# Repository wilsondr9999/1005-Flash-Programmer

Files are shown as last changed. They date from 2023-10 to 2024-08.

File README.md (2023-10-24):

# Flash Programmer
Copyright © 2021 by Dan WIlson

This is a simple PCB, firmware, and software that can read and write binary image files to the Microchip SST39 series of flash ROMs.  These flash ROMs are one of the very few flash ROMs on the market that are still active production and in DIP packages, making them a popular replacement for the difficult-to-find AT28 series of EEPROMs.

This programmer handles the SST39SF010, SST39SF020, and SST39SF040 parts (128KB, 256KB, and 512KB respectively).

This programmer’s PCB design uses all through-hole parts for easy soldering.  The general design is based on Ben Eater’s [Arduino-based Flash Programmer](https://www.youtube.com/watch?v=K88pgWhEb1M), using a microcontroller and shift registers to increase the number of available outputs.  Ben’s microcontroller is the Arduino Nano, here I’m using a Microchip PIC16.

The firmware on the PIC16 implements a command protocol that runs over a serial interface.  The board contains a simple RS232 serial level shifter that allows the PC to communicate with the microcontroller.

On the PC, a command line program is provided to read and write to the flash memory.  The command line program is written in Visual C# with Visual Studio.

You can order the PCBs directly from Oshpark with [this](https://oshpark.com/import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) link.

Several different licenses apply to this repository and the files within.

All schematics and circuit board designs in the project (all KiCAD files) are licensed under the CERN Open Hardware License Version 2 - Strongly Reciprocal (CERN-OHL-S).

All software and firmware code in the project (all MPLAB and Visual Studio files) are licensed under the GNU Affero General Public License v3.0 (AGPL 3.0).

Bill of Materials, pictures, and documentation (i.e. all other files not covered by the other two licenses above) are licensed under the Creative Commons Attribution Share Alike 4.0 International License (CC-BY-SA-4.0).

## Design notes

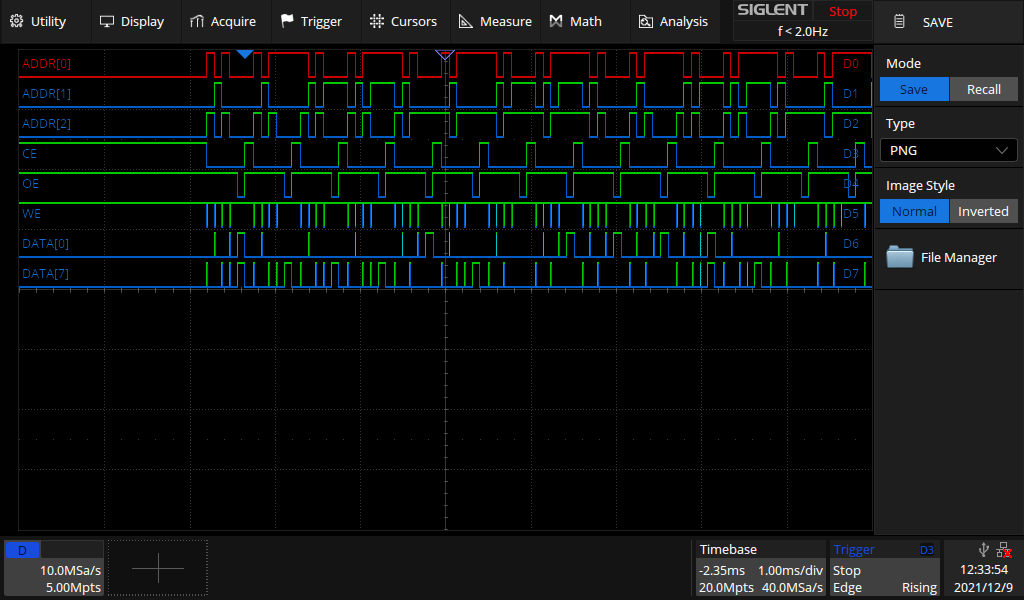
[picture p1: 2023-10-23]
Additional Files/Write2.png

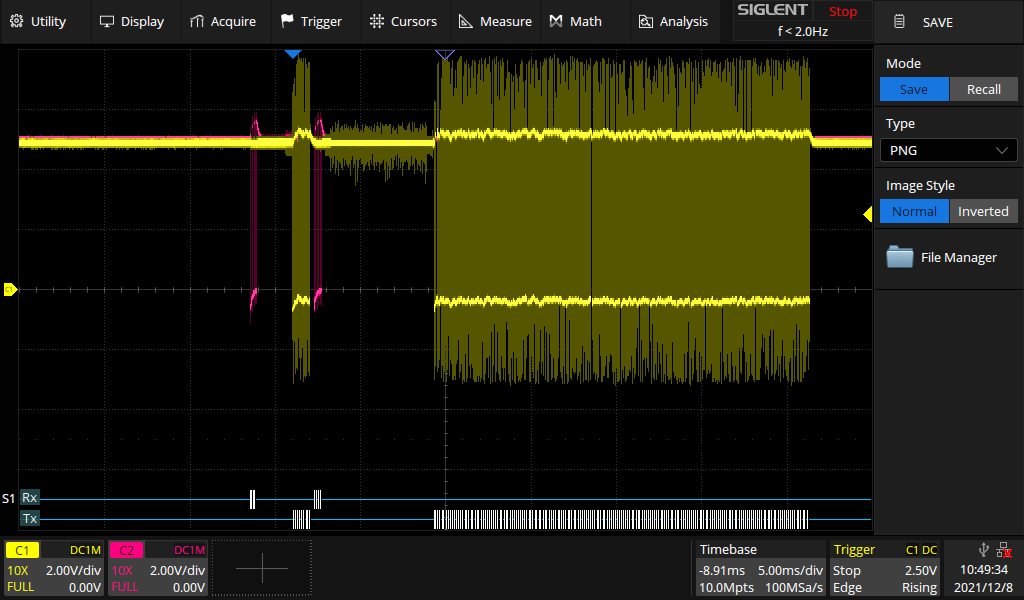
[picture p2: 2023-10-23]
Additional Files/8Mhz.png

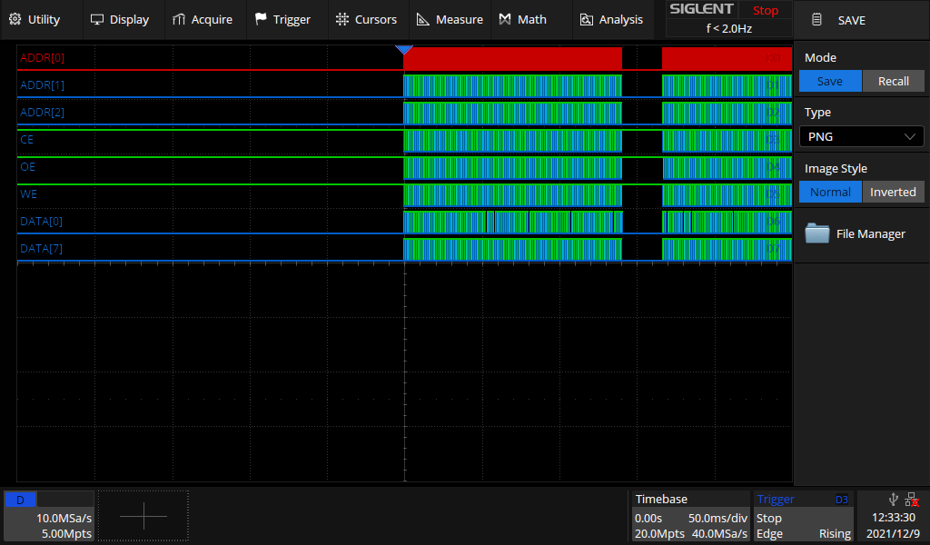
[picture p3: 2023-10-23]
Additional Files/Write1.png

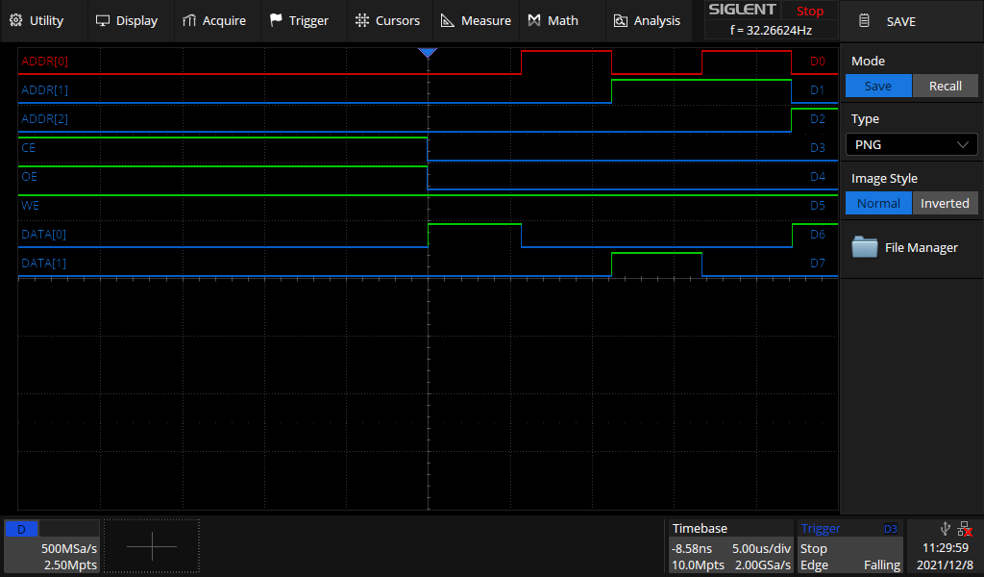
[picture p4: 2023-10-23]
Additional Files/ReadTiming.png

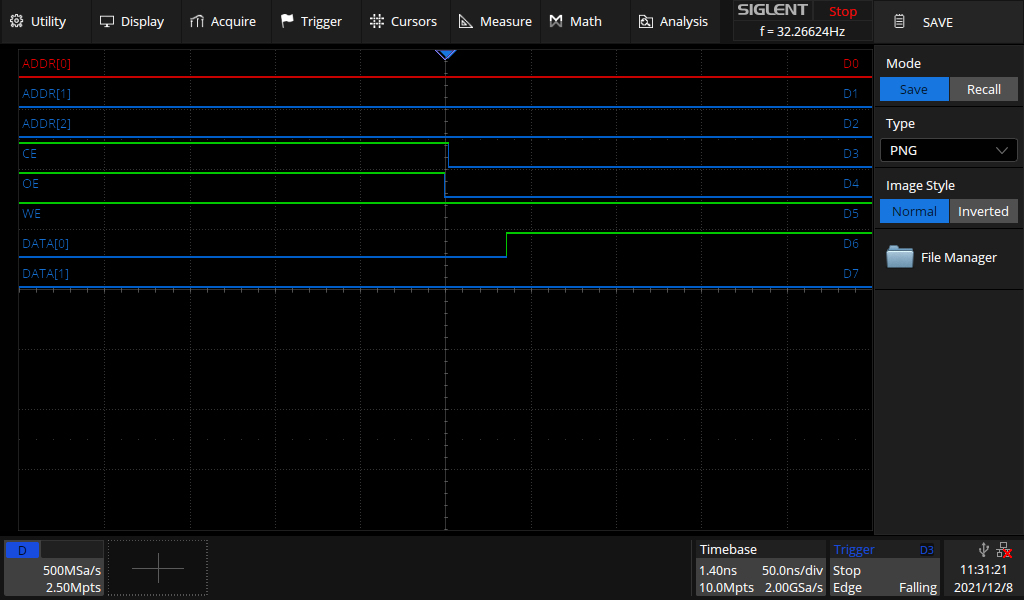
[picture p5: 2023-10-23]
Additional Files/ReadTiming2.png

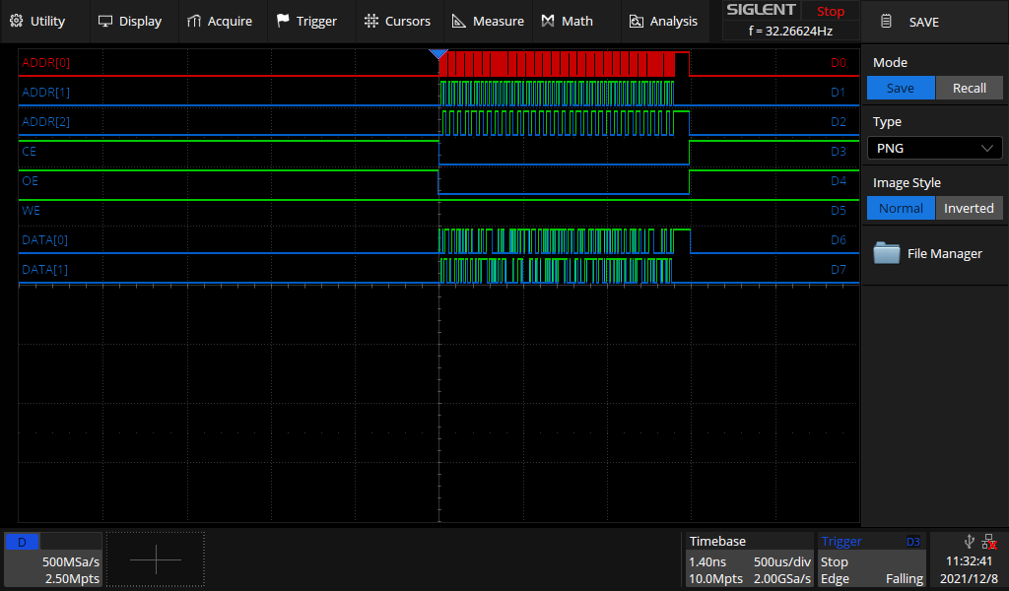
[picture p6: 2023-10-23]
Additional Files/PageRead.png

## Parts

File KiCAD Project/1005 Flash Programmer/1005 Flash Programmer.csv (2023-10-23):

Source: | C:\EE\Projects\1005 Flash Programmer\KiCAD Project\1005 Flash Programmer\1005 Flash Programmer.sch
Date: | 12/26/2021 11:18:50 AM
Tool: | Eeschema (5.1.12)-1
Generator: | C:\Program Files\KiCad\bin\scripting\plugins/bom_csv_grouped_by_value.py
Component Count: | 35
Individual Components:
Item | Qty | Reference(s) | Value | LibPart | Footprint | Datasheet | Category | DK_Datasheet_Link | DK_Detail_Page | Description | Digi-Key_PN | Family | MPN | Manufacturer | Status
 |  | C201 | 0.1uF | Device:C | Capacitor_THT:C_Disc_D4.7mm_W2.5mm_P5.00mm | ~ |  |  |  | CAP CER 0.1UF 50V X7R RADIAL | 445-173588-1-ND | Ceramic Capacitors | FG28X7R1H104KNT06 | TDK Corporation
 |  | C301 | 0.33uF | Device:C | Capacitor_THT:C_Disc_D5.1mm_W3.2mm_P5.00mm | ~ |  |  |  | CAP CER 0.33UF 50V X7R RADIAL | 445-180638-1-ND | Ceramic Capacitors | FA24X7R1H334KNU06 | TDK Corporation
 |  | C302 | 0.1uF | Device:C | Capacitor_THT:C_Disc_D4.7mm_W2.5mm_P5.00mm | ~ |  |  |  | CAP CER 0.1UF 50V X7R RADIAL | 445-173588-1-ND | Ceramic Capacitors | FG28X7R1H104KNT06 | TDK Corporation
 |  | C401 | 0.1uF | Device:C | Capacitor_THT:C_Disc_D4.7mm_W2.5mm_P5.00mm | ~ |  |  |  | CAP CER 0.1UF 50V X7R RADIAL | 445-173588-1-ND | Ceramic Capacitors | FG28X7R1H104KNT06 | TDK Corporation
 |  | C501 | 0.1uF | Device:C | Capacitor_THT:C_Disc_D4.7mm_W2.5mm_P5.00mm | ~ |  |  |  | CAP CER 0.1UF 50V X7R RADIAL | 445-173588-1-ND | Ceramic Capacitors | FG28X7R1H104KNT06 | TDK Corporation
 |  | C502 | 0.1uF | Device:C | Capacitor_THT:C_Disc_D4.7mm_W2.5mm_P5.00mm | ~ |  |  |  | CAP CER 0.1UF 50V X7R RADIAL | 445-173588-1-ND | Ceramic Capacitors | FG28X7R1H104KNT06 | TDK Corporation
 |  | C601 | 0.1uF | Device:C | Capacitor_THT:C_Disc_D4.7mm_W2.5mm_P5.00mm | ~ |  |  |  | CAP CER 0.1UF 50V X7R RADIAL | 445-173588-1-ND | Ceramic Capacitors | FG28X7R1H104KNT06 | TDK Corporation
 |  | D201 | 1N4148 | Diode:1N4148 | Diode_THT:D_DO-35_SOD27_P7.62mm_Horizontal | https://assets.nexperia.com/documents/data-sheet/1N4148_1N4448.pdf |  | https://rocelec.widen.net/view/pdf/bhc41r7lwc/ONSM-S-A0003539415-1.pdf?t.download=true&u=5oefqw |  | DIODE GEN PURP 100V 200MA DO35 | 1N4148FS-ND | Diodes - Rectifiers - Single | 1N4148 | onsemi
 |  | D301 | LED | Device:LED | LED_THT:LED_D5.0mm | https://www.lumex.com/spec/SSL-LX5093USBD.pdf |  | https://www.lumex.com/spec/SSL-LX5093USBD.pdf |  | LED BLUE DIFFUSED T-1 3/4 T/H | 67-1751-ND | LED Indication - Discrete | SSL-LX5093USBD | Lumex Opto/Components Inc.
 |  | D401 | LED | Device:LED | LED_THT:LED_D5.0mm | https://media.digikey.com/pdf/Data%20Sheets/Lite-On%20PDFs/LTL-307A.pdf |  | https://media.digikey.com/pdf/Data%20Sheets/Lite-On%20PDFs/LTL-307A.pdf |  | LED AMBER DIFFUSED T-1 3/4 T/H | 160-1949-ND | LED Indication - Discrete | LTL-307A | LITEON
 |  | D402 | LED | Device:LED | LED_THT:LED_D5.0mm | https://media.digikey.com/pdf/Data%20Sheets/Lite-On%20PDFs/LTL-4233.pdf |  | https://media.digikey.com/pdf/Data%20Sheets/Lite-On%20PDFs/LTL-4233.pdf |  | LED GREEN DIFFUSED T-1 3/4 T/H | 160-1130-ND | LED Indication - Discrete | LTL-4233 | LITEON
 |  | H101 | MountingHole | Mechanical:MountingHole | MountingHole:MountingHole_3.2mm_M3 | ~
 |  | H102 | MountingHole | Mechanical:MountingHole | MountingHole:MountingHole_3.2mm_M3 | ~
 |  | H103 | MountingHole | Mechanical:MountingHole | MountingHole:MountingHole_3.2mm_M3 | ~
 |  | H104 | MountingHole | Mechanical:MountingHole | MountingHole:MountingHole_3.2mm_M3 | ~
 |  | J201 | A-2004-2-4-LP-N-R | dk_Modular-Connectors-Jacks:54602-908LF | digikey-footprints:Ethernet_Jack_54602-908LF |  | Connectors, Interconnects |  | /product-detail/en/amphenol-icc-fci/54602-908LF/609-1046-ND/1001360 | CONN MOD JACK 8P8C R/A UNSHLD | AE10384-ND | Modular Connectors - Jacks | A-2004-2-4-LP-N-R | Amphenol ICC (FCI) | Active
 |  | J301 | Barrel_Jack_Switch | Connector:Barrel_Jack_Switch | digikey-footprints:Barrel_Jack_5.5mmODx2.1mmID_PJ-102A | https://www.cuidevices.com/product/resource/pj-102b.pdf |  | https://www.cuidevices.com/product/resource/pj-102b.pdf |  | CONN PWR JACK 2.5X5.5MM SOLDER | CP-102B-ND | Barrel - Power Connectors | PJ-102B | CUI Devices
 |  | J401 | ICSP | Connector_Generic:Conn_01x05 | Connector_PinHeader_2.54mm:PinHeader_1x05_P2.54mm_Vertical | https://app.adam-tech.com/products/download/data_sheet/201605/ph1-xx-ua-data-sheet.pdf |  | https://app.adam-tech.com/products/download/data_sheet/201605/ph1-xx-ua-data-sheet.pdf |  | CONN HEADER VERT 5POS 2.54MM | 2057-PH1-05-UA-ND | Rectangular Connectors - Headers, Male Pins | PH1-05-UA | Adam Tech
 |  | J601 | 32-6554-10 | DW_Library:32-6554-10 | DW_Footprint:32-6554-10 | https://www.arieselec.com/wp-content/uploads/2020/02/10001-universal-dip-zif-test-socket.pdf |  | https://www.arieselec.com/wp-content/uploads/2020/02/10001-universal-dip-zif-test-socket.pdf |  | CONN IC DIP SOCKET ZIF 32POS TIN | A304-ND | Sockets for ICs, Transistors | 32-6554-10 | Aries Electronics
 |  | Q201 | BC558 | Transistor_BJT:BC558 | Package_TO_SOT_THT:TO-92_Inline | https://www.onsemi.com/pub/Collateral/BC556BTA-D.pdf |  | https://www.nteinc.com/specs/original/BC558.pdf |  | TRANS PNP 30V 100MA TO92-3 | 2368-BC558-ND | Transistors - Bipolar (BJT) - Songle | BC558 | NTE Electronics, Inc
 |  | Q202 | BC548 | Transistor_BJT:BC548 | Package_TO_SOT_THT:TO-92_Inline | https://www.onsemi.com/pub/Collateral/BC550-D.pdf |  | https://rocelec.widen.net/view/pdf/q1kc0zm1fe/FAIRS24942-1.pdf?t.download=true&u=5oefqw |  | TRANS NPN 30V 100MA TO92-3 | 2156-BC548-FS-ND | Transistors - Bipolar (BJT) - Songle | BC548 | Fairchild Semiconductor
 |  | R201 | 10K | Device:R_US | Resistor_THT:R_Axial_DIN0207_L6.3mm_D2.5mm_P10.16mm_Horizontal | ~ |  | https://www.yageo.com/upload/media/product/productsearch/datasheet/lr/YAGEO%20MFR_datasheet_2021v1.pdf |  | RES 10K OHM 1% 1/4W AXIAL | 10.0KXBK-ND | Through Hole Resistors | MFR-25FBF52-10K | YAGEO
 |  | R202 | 10K | Device:R_US | Resistor_THT:R_Axial_DIN0207_L6.3mm_D2.5mm_P10.16mm_Horizontal | ~ |  | https://www.yageo.com/upload/media/product/productsearch/datasheet/lr/YAGEO%20MFR_datasheet_2021v1.pdf |  | RES 10K OHM 1% 1/4W AXIAL | 10.0KXBK-ND | Through Hole Resistors | MFR-25FBF52-10K | YAGEO
 |  | R203 | 4.7K | Device:R_US | Resistor_THT:R_Axial_DIN0207_L6.3mm_D2.5mm_P10.16mm_Horizontal | ~ |  | https://www.yageo.com/upload/media/product/productsearch/datasheet/lr/YAGEO%20MFR_datasheet_2021v1.pdf |  | RES 4.7K OHM 1% 1/4W AXIAL | MFR-25FBF52-4K7-ND | Through Hole Resistors | MFR-25FBF52-4K7 | YAGEO
 |  | R204 | 10K | Device:R_US | Resistor_THT:R_Axial_DIN0207_L6.3mm_D2.5mm_P10.16mm_Horizontal | ~ |  | https://www.yageo.com/upload/media/product/productsearch/datasheet/lr/YAGEO%20MFR_datasheet_2021v1.pdf |  | RES 10K OHM 1% 1/4W AXIAL | 10.0KXBK-ND | Through Hole Resistors | MFR-25FBF52-10K | YAGEO
 |  | R205 | 4.7K | Device:R_US | Resistor_THT:R_Axial_DIN0207_L6.3mm_D2.5mm_P10.16mm_Horizontal | ~ |  | https://www.yageo.com/upload/media/product/productsearch/datasheet/lr/YAGEO%20MFR_datasheet_2021v1.pdf |  | RES 4.7K OHM 1% 1/4W AXIAL | MFR-25FBF52-4K7-ND | Through Hole Resistors | MFR-25FBF52-4K7 | YAGEO
 |  | R206 | 4.7K | Device:R_US | Resistor_THT:R_Axial_DIN0207_L6.3mm_D2.5mm_P10.16mm_Horizontal | ~ |  | https://www.yageo.com/upload/media/product/productsearch/datasheet/lr/YAGEO%20MFR_datasheet_2021v1.pdf |  | RES 4.7K OHM 1% 1/4W AXIAL | MFR-25FBF52-4K7-ND | Through Hole Resistors | MFR-25FBF52-4K7 | YAGEO
 |  | R301 | 300 | Device:R | Resistor_THT:R_Axial_DIN0207_L6.3mm_D2.5mm_P10.16mm_Horizontal | https://www.yageo.com/upload/media/product/productsearch/datasheet/lr/YAGEO%20MFR_datasheet_2021v1.pdf |  | https://www.yageo.com/upload/media/product/productsearch/datasheet/lr/YAGEO%20MFR_datasheet_2021v1.pdf |  | RES 300 OHM 1% 1/4W AXIAL | MFR-25FBF52-300R-ND | Through Hole Resistors | MFR-25FBF52-300R | YAGEO
 |  | R401 | 10K | Device:R | Resistor_THT:R_Axial_DIN0207_L6.3mm_D2.5mm_P10.16mm_Horizontal | ~ |  | https://www.yageo.com/upload/media/product/productsearch/datasheet/lr/YAGEO%20MFR_datasheet_2021v1.pdf |  | RES 10K OHM 1% 1/4W AXIAL | 10.0KXBK-ND | Through Hole Resistors | MFR-25FBF52-10K | YAGEO
 |  | R402 | 300 | Device:R | Resistor_THT:R_Axial_DIN0207_L6.3mm_D2.5mm_P10.16mm_Horizontal | https://www.yageo.com/upload/media/product/productsearch/datasheet/lr/YAGEO%20MFR_datasheet_2021v1.pdf |  | https://www.yageo.com/upload/media/product/productsearch/datasheet/lr/YAGEO%20MFR_datasheet_2021v1.pdf |  | RES 300 OHM 1% 1/4W AXIAL | MFR-25FBF52-300R-ND | Through Hole Resistors | MFR-25FBF52-300R | YAGEO
 |  | R403 | 300 | Device:R | Resistor_THT:R_Axial_DIN0207_L6.3mm_D2.5mm_P10.16mm_Horizontal | https://www.yageo.com/upload/media/product/productsearch/datasheet/lr/YAGEO%20MFR_datasheet_2021v1.pdf |  | https://www.yageo.com/upload/media/product/productsearch/datasheet/lr/YAGEO%20MFR_datasheet_2021v1.pdf |  | RES 300 OHM 1% 1/4W AXIAL | MFR-25FBF52-300R-ND | Through Hole Resistors | MFR-25FBF52-300R | YAGEO
 |  | U301 | L7805CV | dk_PMIC-Voltage-Regulators-Linear:L7805CV | digikey-footprints:TO-220-3 | http://www.st.com/content/ccc/resource/technical/document/datasheet/41/4f/b3/b0/12/d4/47/88/CD00000444.pdf/files/CD00000444.pdf/jcr:content/translations/en.CD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 | Integrated Circuits (ICs) | http://www.st.com/content/ccc/resource/technical/document/datasheet/41/4f/b3/b0/12/d4/47/88/CD00000444.pdf/files/CD00000444.pdf/jcr:content/translations/en.CD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 | /product-detail/en/stmicroelectronics/L7805CV/497-1443-5-ND/585964 | IC REG LINEAR 5V 1.5A TO220AB | 497-1443-5-ND | PMIC - Voltage Regulators - Linear | L7805CV | STMicroelectronics | Active
 |  | U401 | PIC16F15256-xSP | MCU_Microchip_PIC16:PIC16F15356-xSP | Package_DIP:DIP-28_W7.62mm | https://ww1.microchip.com/downloads/en/DeviceDoc/PIC16F15256-74-75-76-28-40-Pin-Microcontrollers-40002305B.pdf |  | https://ww1.microchip.com/downloads/en/DeviceDoc/PIC16F15256-74-75-76-28-40-Pin-Microcontrollers-40002305B.pdf |  | IC MCU 8BIT 28KB FLASH 28SPDIP | 150-PIC16F15256-I/SP-ND | Embedded - Microcontrollers | PIC16F15256-I/SP | Microchip Technology
 |  | U501 | SN74HC595NE4 | dk_Logic-Shift-Registers:SN74HC595N | digikey-footprints:DIP-16_W7.62mm | https://www.ti.com/general/docs/suppproductinfo.tsp?distId=10 | Integrated Circuits (ICs) | https://www.ti.com/general/docs/suppproductinfo.tsp?distId=10 | https://www.digikey.com/en/products/detail/texas-instruments/SN74HC595NE4/1571270 | IC SHIFT REGISTER 8BIT 16-DIP | 296-36142-5-ND | Logic - Shift Registers | SN74HC595NE4 | Texas Instruments | Active
 |  | U502 | SN74HC595NE4 | dk_Logic-Shift-Registers:SN74HC595N | digikey-footprints:DIP-16_W7.62mm | https://www.ti.com/general/docs/suppproductinfo.tsp?distId=10 | Integrated Circuits (ICs) | https://www.ti.com/general/docs/suppproductinfo.tsp?distId=10 | https://www.digikey.com/en/products/detail/texas-instruments/SN74HC595NE4/1571270 | IC SHIFT REGISTER 8BIT 16-DIP | 296-36142-5-ND | Logic - Shift Registers | SN74HC595NE4 | Texas Instruments | Active
Collated Components:
Item | Qty | Reference(s) | Value | LibPart | Footprint | Datasheet | Category | DK_Datasheet_Link | DK_Detail_Page | Description | Digi-Key_PN | Family | MPN | Manufacturer | Status
1 | 6 | C201, C302, C401, C501, C502, C601 | 0.1uF | Device:C | Capacitor_THT:C_Disc_D4.7mm_W2.5mm_P5.00mm | ~ |  |  |  | CAP CER 0.1UF 50V X7R RADIAL | 445-173588-1-ND | Ceramic Capacitors | FG28X7R1H104KNT06 | TDK Corporation
2 | 1 | C301 | 0.33uF | Device:C | Capacitor_THT:C_Disc_D5.1mm_W3.2mm_P5.00mm | ~ |  |  |  | CAP CER 0.33UF 50V X7R RADIAL | 445-180638-1-ND | Ceramic Capacitors | FA24X7R1H334KNU06 | TDK Corporation
3 | 1 | D201 | 1N4148 | Diode:1N4148 | Diode_THT:D_DO-35_SOD27_P7.62mm_Horizontal | https://assets.nexperia.com/documents/data-sheet/1N4148_1N4448.pdf |  | https://rocelec.widen.net/view/pdf/bhc41r7lwc/ONSM-S-A0003539415-1.pdf?t.download=true&u=5oefqw |  | DIODE GEN PURP 100V 200MA DO35 | 1N4148FS-ND | Diodes - Rectifiers - Single | 1N4148 | onsemi
4 | 3 | D301, D401, D402 | LED | Device:LED | LED_THT:LED_D5.0mm | https://www.lumex.com/spec/SSL-LX5093USBD.pdf |  | https://www.lumex.com/spec/SSL-LX5093USBD.pdf |  | LED BLUE DIFFUSED T-1 3/4 T/H | 67-1751-ND | LED Indication - Discrete | SSL-LX5093USBD | Lumex Opto/Components Inc.
5 | 4 | H101, H102, H103, H104 | MountingHole | Mechanical:MountingHole | MountingHole:MountingHole_3.2mm_M3 | ~
6 | 1 | J201 | A-2004-2-4-LP-N-R | dk_Modular-Connectors-Jacks:54602-908LF | digikey-footprints:Ethernet_Jack_54602-908LF |  | Connectors, Interconnects |  | /product-detail/en/amphenol-icc-fci/54602-908LF/609-1046-ND/1001360 | CONN MOD JACK 8P8C R/A UNSHLD | AE10384-ND | Modular Connectors - Jacks | A-2004-2-4-LP-N-R | Amphenol ICC (FCI) | Active
7 | 1 | J301 | Barrel_Jack_Switch | Connector:Barrel_Jack_Switch | digikey-footprints:Barrel_Jack_5.5mmODx2.1mmID_PJ-102A | https://www.cuidevices.com/product/resource/pj-102b.pdf |  | https://www.cuidevices.com/product/resource/pj-102b.pdf |  | CONN PWR JACK 2.5X5.5MM SOLDER | CP-102B-ND | Barrel - Power Connectors | PJ-102B | CUI Devices
8 | 1 | J401 | ICSP | Connector_Generic:Conn_01x05 | Connector_PinHeader_2.54mm:PinHeader_1x05_P2.54mm_Vertical | https://app.adam-tech.com/products/download/data_sheet/201605/ph1-xx-ua-data-sheet.pdf |  | https://app.adam-tech.com/products/download/data_sheet/201605/ph1-xx-ua-data-sheet.pdf |  | CONN HEADER VERT 5POS 2.54MM | 2057-PH1-05-UA-ND | Rectangular Connectors - Headers, Male Pins | PH1-05-UA | Adam Tech
9 | 1 | J601 | 32-6554-10 | DW_Library:32-6554-10 | DW_Footprint:32-6554-10 | https://www.arieselec.com/wp-content/uploads/2020/02/10001-universal-dip-zif-test-socket.pdf |  | https://www.arieselec.com/wp-content/uploads/2020/02/10001-universal-dip-zif-test-socket.pdf |  | CONN IC DIP SOCKET ZIF 32POS TIN | A304-ND | Sockets for ICs, Transistors | 32-6554-10 | Aries Electronics
10 | 1 | Q201 | BC558 | Transistor_BJT:BC558 | Package_TO_SOT_THT:TO-92_Inline | https://www.onsemi.com/pub/Collateral/BC556BTA-D.pdf |  | https://www.nteinc.com/specs/original/BC558.pdf |  | TRANS PNP 30V 100MA TO92-3 | 2368-BC558-ND | Transistors - Bipolar (BJT) - Songle | BC558 | NTE Electronics, Inc
11 | 1 | Q202 | BC548 | Transistor_BJT:BC548 | Package_TO_SOT_THT:TO-92_Inline | https://www.onsemi.com/pub/Collateral/BC550-D.pdf |  | https://rocelec.widen.net/view/pdf/q1kc0zm1fe/FAIRS24942-1.pdf?t.download=true&u=5oefqw |  | TRANS NPN 30V 100MA TO92-3 | 2156-BC548-FS-ND | Transistors - Bipolar (BJT) - Songle | BC548 | Fairchild Semiconductor
12 | 3 | R201, R202, R204 | 10K | Device:R_US | Resistor_THT:R_Axial_DIN0207_L6.3mm_D2.5mm_P10.16mm_Horizontal | ~ |  | https://www.yageo.com/upload/media/product/productsearch/datasheet/lr/YAGEO%20MFR_datasheet_2021v1.pdf |  | RES 10K OHM 1% 1/4W AXIAL | 10.0KXBK-ND | Through Hole Resistors | MFR-25FBF52-10K | YAGEO
13 | 3 | R203, R205, R206 | 4.7K | Device:R_US | Resistor_THT:R_Axial_DIN0207_L6.3mm_D2.5mm_P10.16mm_Horizontal | ~ |  | https://www.yageo.com/upload/media/product/productsearch/datasheet/lr/YAGEO%20MFR_datasheet_2021v1.pdf |  | RES 4.7K OHM 1% 1/4W AXIAL | MFR-25FBF52-4K7-ND | Through Hole Resistors | MFR-25FBF52-4K7 | YAGEO
14 | 3 | R301, R402, R403 | 300 | Device:R | Resistor_THT:R_Axial_DIN0207_L6.3mm_D2.5mm_P10.16mm_Horizontal | https://www.yageo.com/upload/media/product/productsearch/datasheet/lr/YAGEO%20MFR_datasheet_2021v1.pdf |  | https://www.yageo.com/upload/media/product/productsearch/datasheet/lr/YAGEO%20MFR_datasheet_2021v1.pdf |  | RES 300 OHM 1% 1/4W AXIAL | MFR-25FBF52-300R-ND | Through Hole Resistors | MFR-25FBF52-300R | YAGEO
15 | 1 | R401 | 10K | Device:R | Resistor_THT:R_Axial_DIN0207_L6.3mm_D2.5mm_P10.16mm_Horizontal | ~ |  | https://www.yageo.com/upload/media/product/productsearch/datasheet/lr/YAGEO%20MFR_datasheet_2021v1.pdf |  | RES 10K OHM 1% 1/4W AXIAL | 10.0KXBK-ND | Through Hole Resistors | MFR-25FBF52-10K | YAGEO
16 | 1 | U301 | L7805CV | dk_PMIC-Voltage-Regulators-Linear:L7805CV | digikey-footprints:TO-220-3 | http://www.st.com/content/ccc/resource/technical/document/datasheet/41/4f/b3/b0/12/d4/47/88/CD00000444.pdf/files/CD00000444.pdf/jcr:content/translations/en.CD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 | Integrated Circuits (ICs) | http://www.st.com/content/ccc/resource/technical/document/datasheet/41/4f/b3/b0/12/d4/47/88/CD00000444.pdf/files/CD00000444.pdf/jcr:content/translations/en.CD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 | /product-detail/en/stmicroelectronics/L7805CV/497-1443-5-ND/585964 | IC REG LINEAR 5V 1.5A TO220AB | 497-1443-5-ND | PMIC - Voltage Regulators - Linear | L7805CV | STMicroelectronics | Active
17 | 1 | U401 | PIC16F15256-xSP | MCU_Microchip_PIC16:PIC16F15356-xSP | Package_DIP:DIP-28_W7.62mm | https://ww1.microchip.com/downloads/en/DeviceDoc/PIC16F15256-74-75-76-28-40-Pin-Microcontrollers-40002305B.pdf |  | https://ww1.microchip.com/downloads/en/DeviceDoc/PIC16F15256-74-75-76-28-40-Pin-Microcontrollers-40002305B.pdf |  | IC MCU 8BIT 28KB FLASH 28SPDIP | 150-PIC16F15256-I/SP-ND | Embedded - Microcontrollers | PIC16F15256-I/SP | Microchip Technology
18 | 2 | U501, U502 | SN74HC595NE4 | dk_Logic-Shift-Registers:SN74HC595N | digikey-footprints:DIP-16_W7.62mm | https://www.ti.com/general/docs/suppproductinfo.tsp?distId=10 | Integrated Circuits (ICs) | https://www.ti.com/general/docs/suppproductinfo.tsp?distId=10 | https://www.digikey.com/en/products/detail/texas-instruments/SN74HC595NE4/1571270 | IC SHIFT REGISTER 8BIT 16-DIP | 296-36142-5-ND | Logic - Shift Registers | SN74HC595NE4 | Texas Instruments | Active

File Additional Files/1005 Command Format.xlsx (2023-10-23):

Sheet: Sheet1
1005 Flash Programmer Command Format
Read Command
Command ID | Address to Read from | Bytes to Read
0x80 | 0x000000 | 0xff |  |  |  | Valid Address Ranges
 |  |  |  | 0x80 | Read Memory | Model | Size (B) |  | Address L | Address H
 |  |  |  | 0x000000 | Address to read from, 3 bytes | SST39SF010A | 131072 | 0x020000 | 0x000000 | 0x01ffff
 |  |  |  | 0xff | Number of bytes to read, 0x01-0xff or 0x00 to read 256 bytes | SST39SF020A | 262144 | 0x040000 | 0x000000 | 0x03ffff
 |  |  |  |  |  | SST39SF030A | 524288 | 0x080000 | 0x000000 | 0x07ffff
< 0x80 | Ack, PIC has no bytes to return
< 0x81 | Ack, PIC has bytes to return
< ### | Number of bytes to return
< ### | Bytes from Flash
Write Command
Command ID | Address to Write to | Bytes to Write
0x81 | 0x000000 | 0xff
 |  |  |  | 0x81 | Write Memory
 |  |  |  | 0x000000 | Address to write to, 3 bytes
 |  |  |  | 0xff | Number of bytes to write, 0x01-0xff or 0x00 to write 256 bytes
< 0x91 | Ack, PIC requests you send bytes
< 0x[Length] | Request you send length bytes
> ### | Bytes to write
< 0x80 | Ack, PIC has no bytes to return
Sector Erase Command
Command ID | Address of block to erase | Padding Byte
0x82 | 0x000000 | 0x00
 |  |  |  | 0x82 | Erase Memory
< 0x80 | Ack, PIC has no bytes to return |  |  | 0x000000 | Address of start of block to erase (will get ANDed with 0x0xfffc00 to get 4KB boundary)
 |  |  |  | 0x00 | Padding byte
Chip ID Command
Command ID | Padding Bytes | Padding Byte
0x83 | 0x000000 | 0x00 |  | 0x83 | Get Chip ID
 |  |  |  | 0x000000 | Padding bytes
< 0x81 02 | Ack, PIC has 2 bytes to return |  |  | 0x00 | Padding byte
< ### | Chip ID
< 0xC0 | Error, no bytes to return
Software Reset Command
Command ID | Padding Bytes | Padding Byte
0xbf | 0x000000 | 0x00 |  | 0x83 | Get Chip ID
 |  |  |  | 0x000000 | Padding bytes
< ATR |  |  |  | 0x00 | Padding byte
Chip Erase Command
Command ID | Padding Bytes | Padding Byte
0x84 | 0x000000 | 0x00 |  | 0x84 | Erase entire chip
 |  |  |  | 0x000000 | Padding bytes
< 0x80 | Ack, PIC has no bytes to return |  |  | 0x00 | Padding byte
PICFLash Command Line
Cmd | Address | Length | con/filename
r | 000000 | 000000 | con/filename
w | 000000 | 000000 | filename
g | 000000 | 000000 | filename
i | 000000 | 000000 | con

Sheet: Sheet2
ATR
TS | Initial Character | 0x3b | Direct convention, high bits = 1, LSB first
T0 | Format byte | 0x38 | Includes Interface bytes TA1, TB1 and 8 historical bytes
TA1 | Interface byte 1 | 0x45 | Encode a 12 MHz clock (Fi=1116, 0100) with a 16 divider (Di=16, 0101), Fi/Di = 68 clock cycles per byte
TB1 | Interface byte 2 | 0x00 | No longer used (previously used to describe programming voltage and current)
Hist |  | F
 |  | l
 |  | s
 |  | h
 |  | P
 |  | r
 |  | g
 | Version | 0x12

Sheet: Sheet3
Command Line Options
 |  | Defaults
-b | Baud rate | 115200
-c | Com port specification | COM1
 |  |  | Display | File
 | Read Flash | [Default] | X | X
-w | Write to Flash | Read if not present |  | X
-f | Format Flash
-e | Erase one or more sectors
-i | Get Chip identification
-g | Generate Random File |  |  | X
-d | Display to console | Reads/writes from file if not present
-s | Starting address | 0x000000
-l | Length | [Size of Flash]
-n | Ending address | [Last address in Flash]
-o | Offset in file | 0x000000
 | Verify command?

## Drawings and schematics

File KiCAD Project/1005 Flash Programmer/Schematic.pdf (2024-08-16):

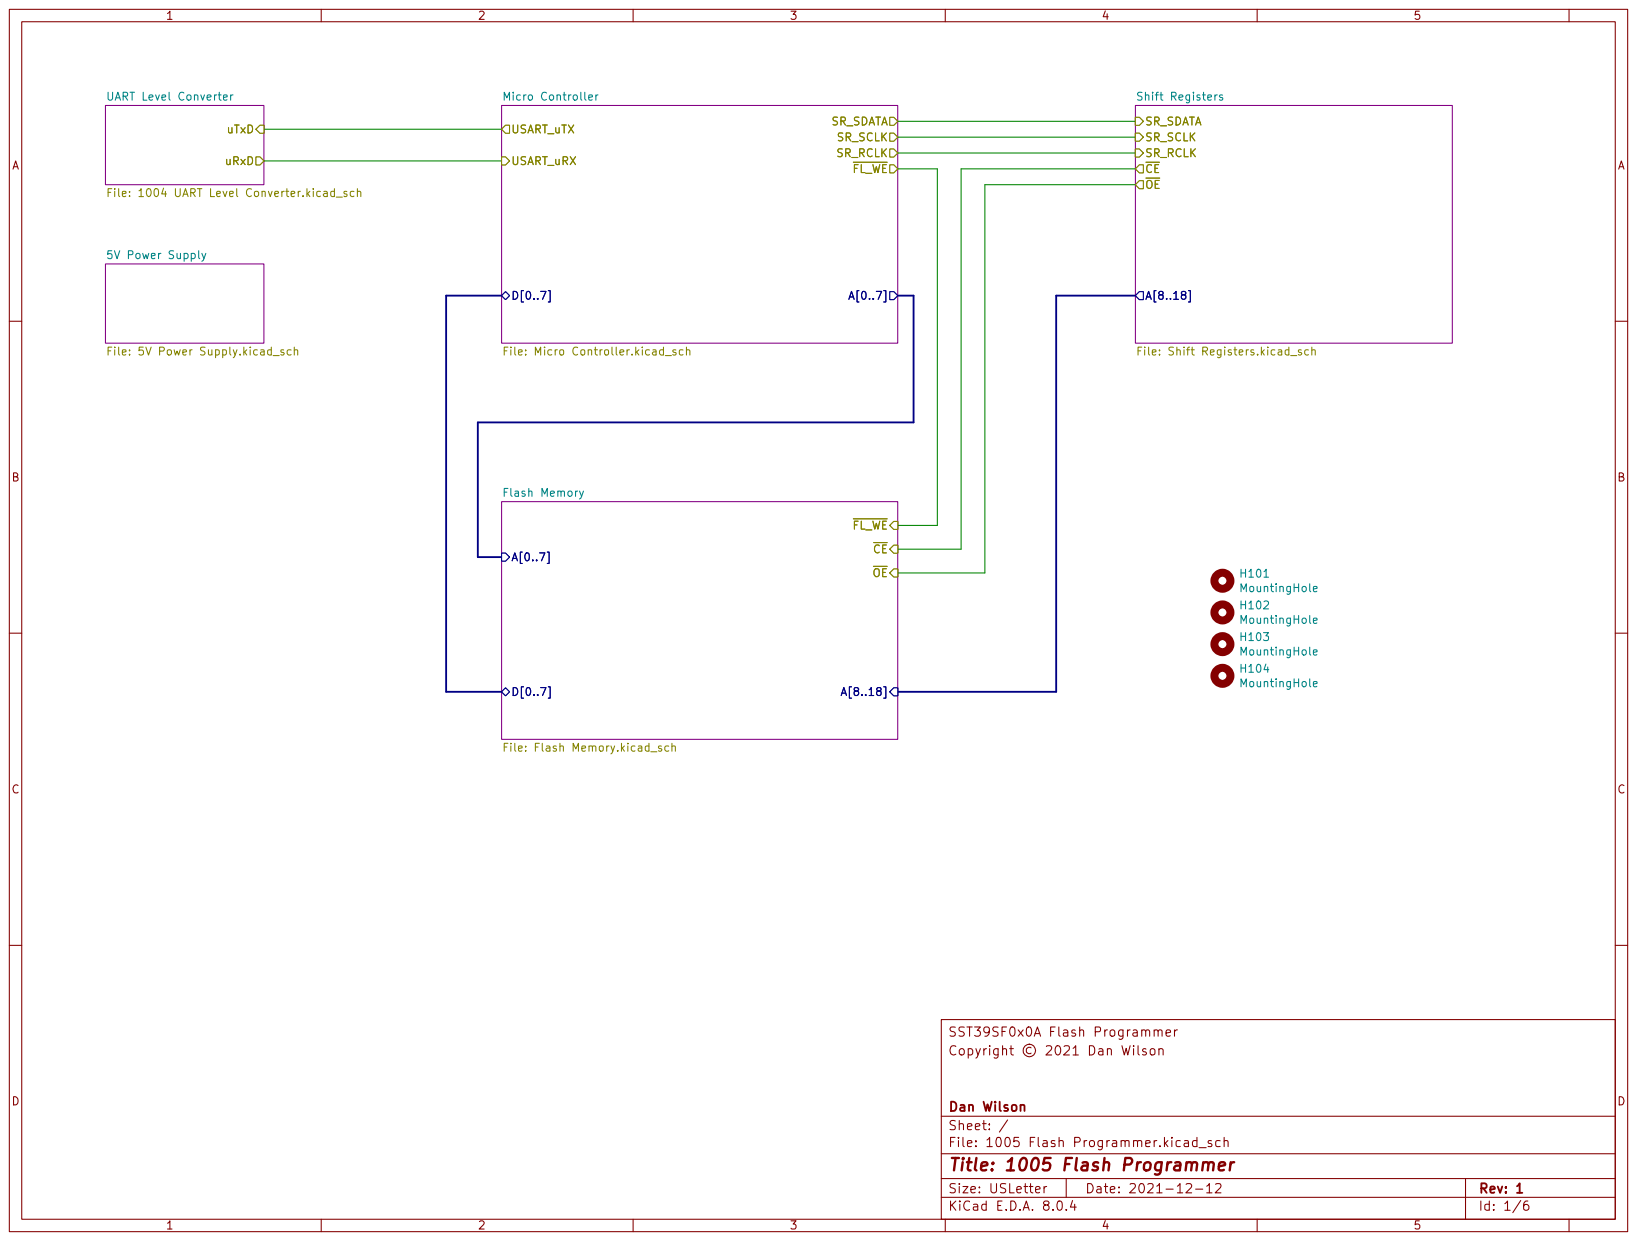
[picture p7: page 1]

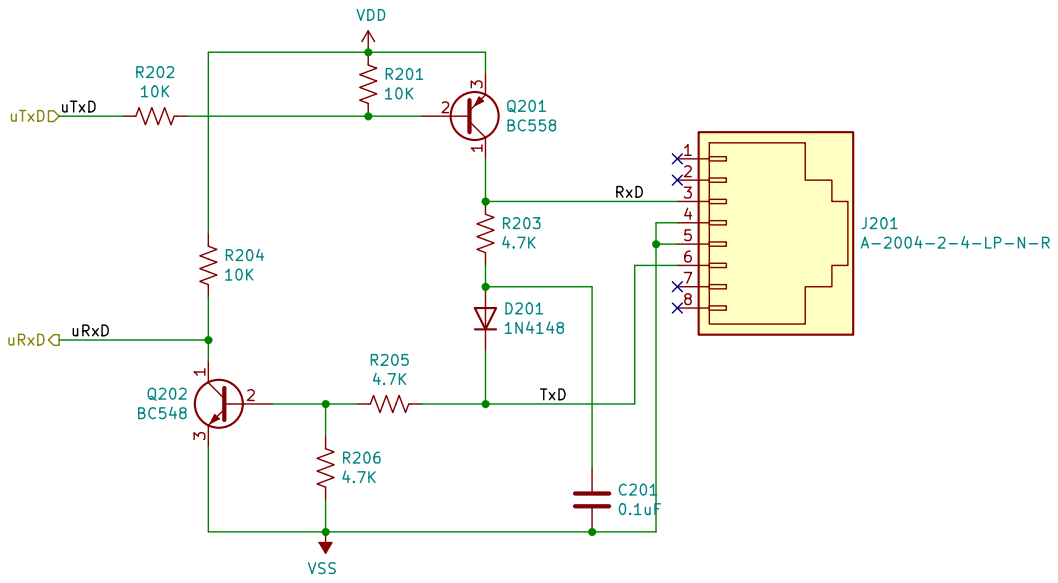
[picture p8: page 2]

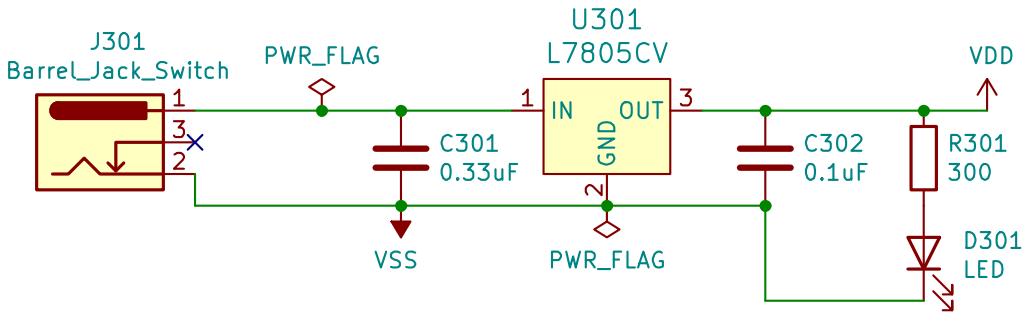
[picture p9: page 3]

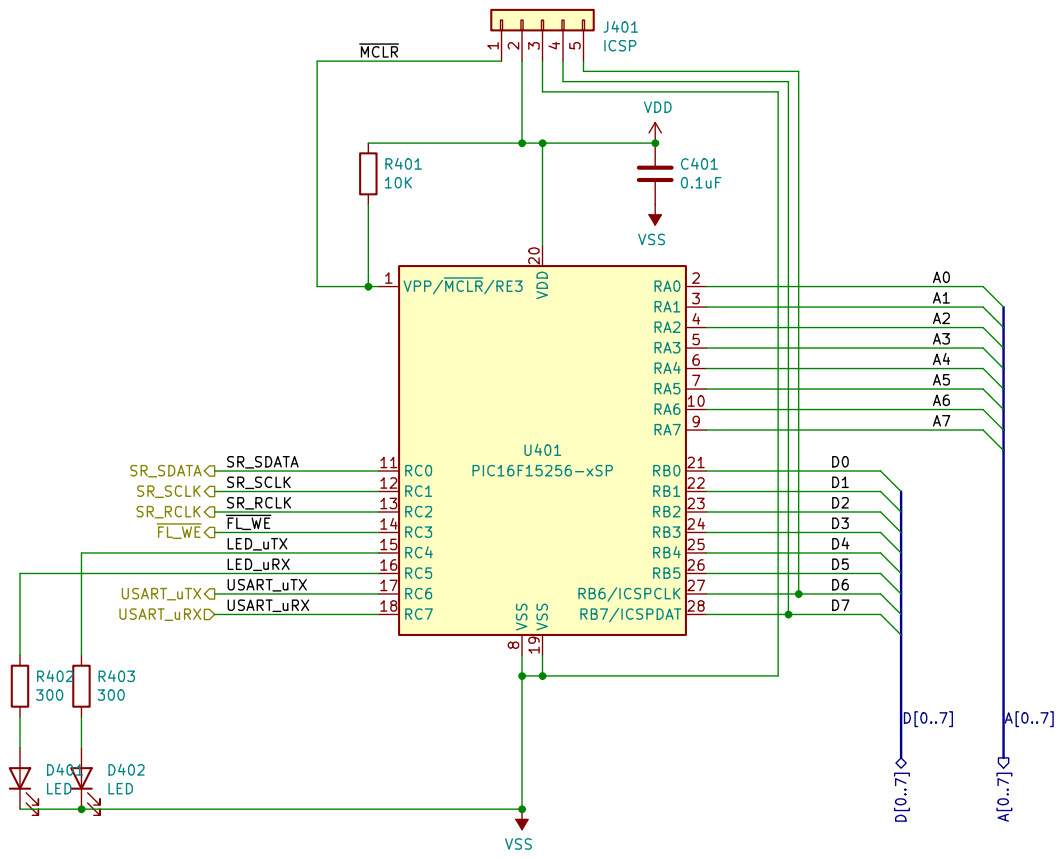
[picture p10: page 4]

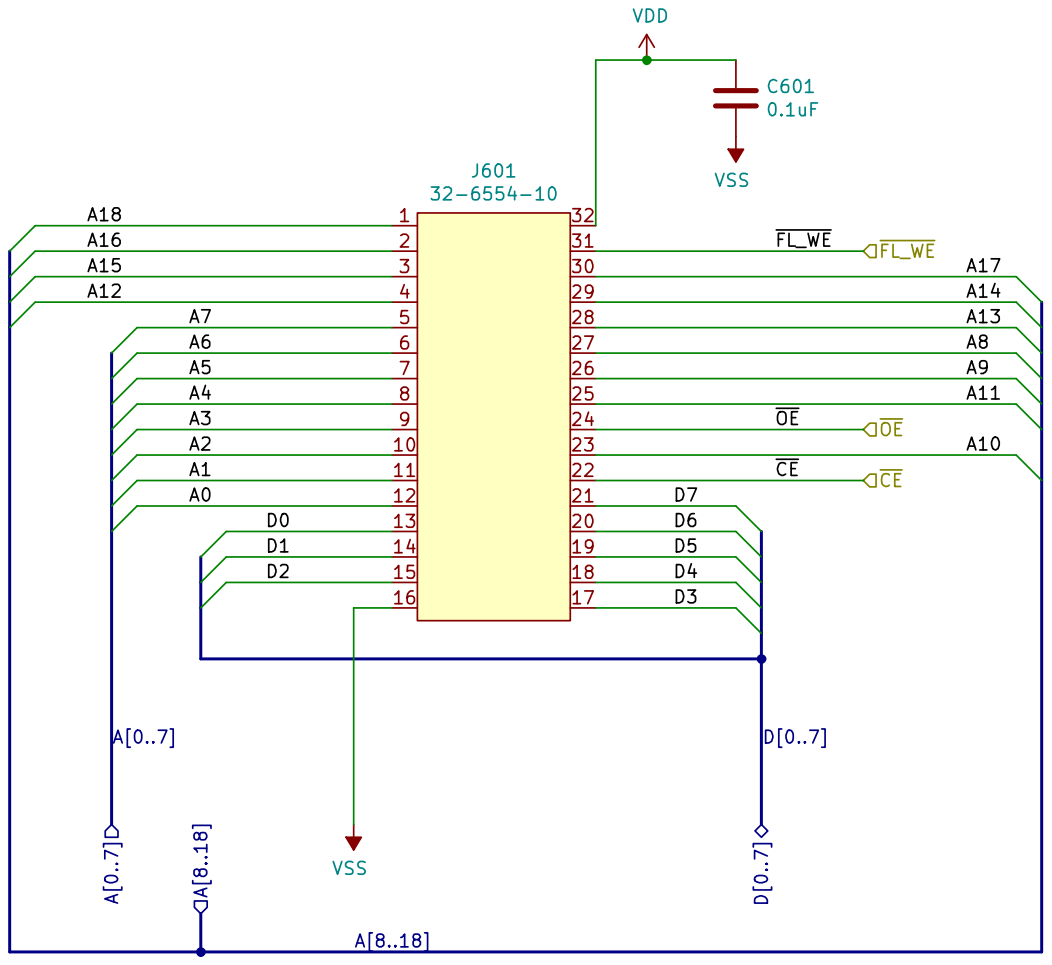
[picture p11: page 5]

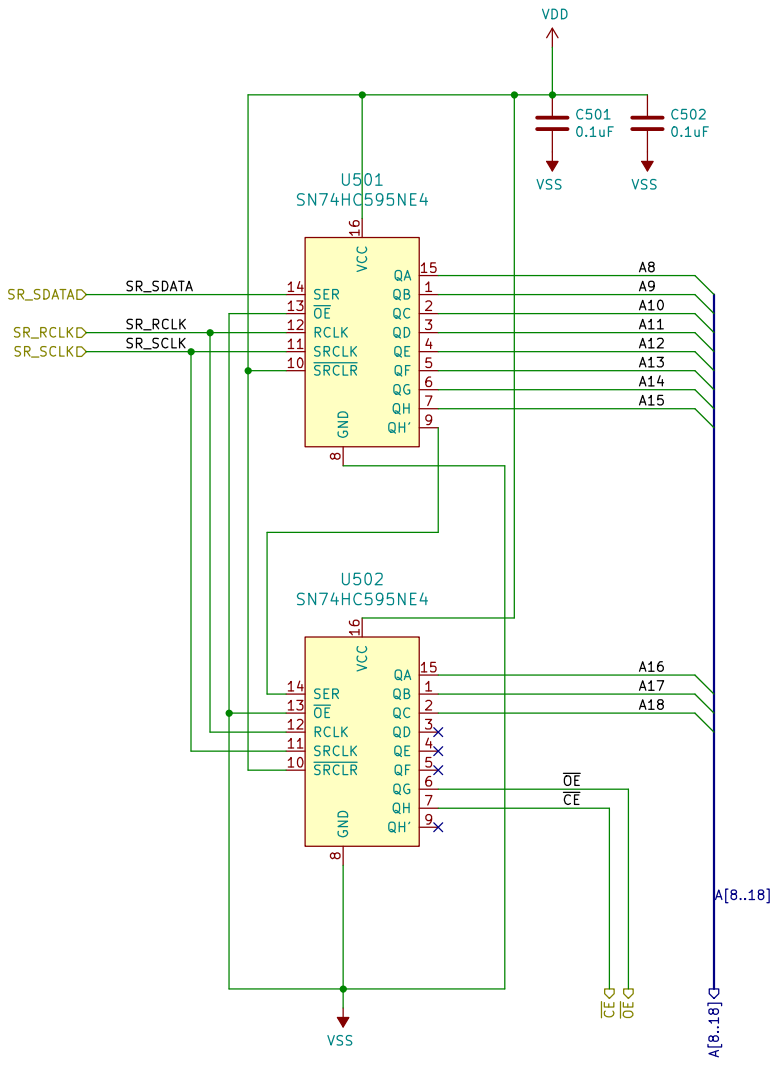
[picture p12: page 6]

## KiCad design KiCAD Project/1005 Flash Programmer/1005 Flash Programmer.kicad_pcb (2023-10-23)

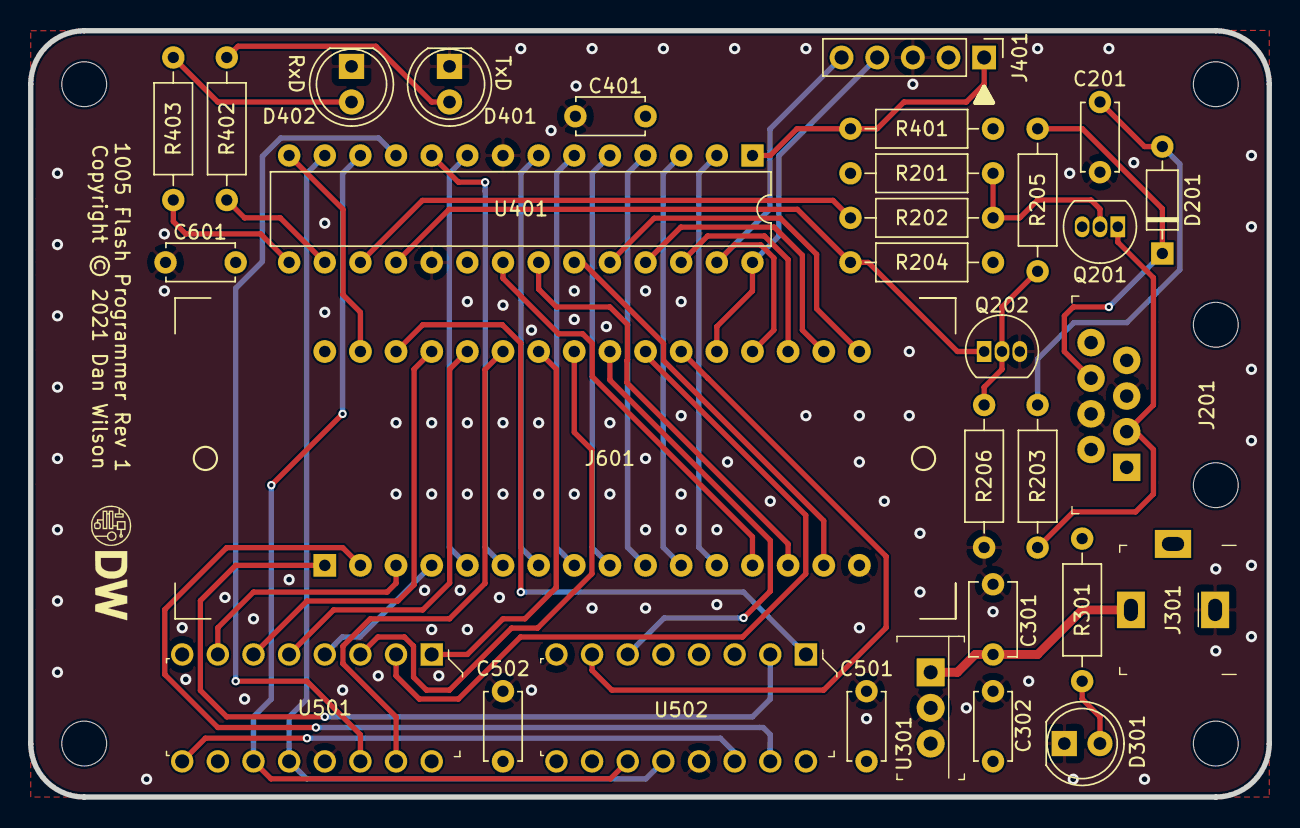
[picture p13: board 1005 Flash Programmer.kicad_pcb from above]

Board: 4 copper layers, 88.3 x 54.6 mm, 35 parts (0 on the bottom side), 50 nets.

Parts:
C201, C302, C401, C501, C502, C601: 0.1uF; C_Disc_D4.7mm_W2.5mm_P5.00mm
C301: 0.33uF; C_Disc_D5.1mm_W3.2mm_P5.00mm
D201: 1N4148; D_DO-35_SOD27_P7.62mm_Horizontal
D301, D401, D402: LED; LED_D5.0mm
H101, H102, H103, H104: MountingHole; MountingHole_3.2mm_M3
J201: A-2004-2-4-LP-N-R; Ethernet_Jack_54602-908LF
J301: Barrel_Jack_Switch; Barrel_Jack_5.5mmODx2.1mmID_PJ-102A
J401: ICSP; PinHeader_1x05_P2.54mm_Vertical
J601: 32-6554-10
Q201: BC558; TO-92_Inline
Q202: BC548; TO-92_Inline
R201, R202, R204, R401: 10K; R_Axial_DIN0207_L6.3mm_D2.5mm_P10.16mm_Horizontal
R203, R205, R206: 4.7K; R_Axial_DIN0207_L6.3mm_D2.5mm_P10.16mm_Horizontal
R301, R402, R403: 300; R_Axial_DIN0207_L6.3mm_D2.5mm_P10.16mm_Horizontal
U301: L7805CV; TO-220-3
U401: PIC16F15256-xSP; DIP-28_W7.62mm
U501, U502: SN74HC595NE4; DIP-16_W7.62mm

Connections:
/Flash Memory/A0: J601.12, U401.2
/Flash Memory/A1: J601.11, U401.3
/Flash Memory/A2: J601.10, U401.4
/Flash Memory/A3: J601.9, U401.5
/Flash Memory/A4: J601.8, U401.6
/Flash Memory/A5: J601.7, U401.7
/Flash Memory/A6: J601.6, U401.10
/Flash Memory/A7: J601.5, U401.9
/Flash Memory/A8: J601.27, U501.15
/Flash Memory/A9: J601.26, U501.1
/Flash Memory/A10: J601.23, U501.2
/Flash Memory/A11: J601.25, U501.3
/Flash Memory/A12: J601.4, U501.4
/Flash Memory/A13: J601.28, U501.5
/Flash Memory/A14: J601.29, U501.6
/Flash Memory/A15: J601.3, U501.7
/Flash Memory/A16: J601.2, U502.15
/Flash Memory/A17: J601.30, U502.1
/Flash Memory/A18: J601.1, U502.2
/Flash Memory/D0: J601.13, U401.21
/Flash Memory/D1: J601.14, U401.22
/Flash Memory/D2: J601.15, U401.23
/Flash Memory/D3: J601.17, U401.24
/Flash Memory/D4: J601.18, U401.25
/Flash Memory/D5: J601.19, U401.26
/Flash Memory/D6: J401.5, J601.20, U401.27
/Flash Memory/D7: J401.4, J601.21, U401.28
/Flash Memory/~CE: J601.22, U502.7
/Flash Memory/~FL_WE: J601.31, U401.14
/Flash Memory/~OE: J601.24, U502.6
/Micro Controller/LED_uRX: R402.1, U401.16
/Micro Controller/LED_uTX: R403.1, U401.15
/Micro Controller/SR_RCLK: U401.13, U501.12, U502.12
/Micro Controller/SR_SCLK: U401.12, U501.11, U502.11
/Micro Controller/SR_SDATA: U401.11, U501.14
/Micro Controller/USART_uRX: Q202.1, R204.2, U401.18
/Micro Controller/USART_uTX: R202.2, U401.17
/Micro Controller/~MCLR: J401.1, R401.2, U401.1
/UART Level Converter/RxD: J201.3, Q201.1, R203.1
/UART Level Converter/TxD: D201.1, J201.6, R205.1
unnamed: C201.1, D201.2, R203.2
unnamed: C301.1, J301.1, U301.1
unnamed: D301.2, R301.2
unnamed: D401.2, R402.2
unnamed: D402.2, R403.2
unnamed: Q201.2, R201.2, R202.1
unnamed: Q202.2, R205.2, R206.1
unnamed: U501.9, U502.14
VDD: C302.1, C401.1, C501.1, C502.1, C601.1, J401.2, J601.32, Q201.3, R201.1, R204.1, R301.1, R401.1, U301.3, U401.20, U501.10, U501.16, U502.10, U502.16
VSS: C201.2, C301.2, C302.2, C401.2, C501.2, C502.2, C601.2, D301.1, D401.1, D402.1, J201.4, J201.5, J301.2, J401.3, J601.16, Q202.3, R206.2, U301.2, U401.8, U401.19, U501.8, U501.13, U502.8, U502.13

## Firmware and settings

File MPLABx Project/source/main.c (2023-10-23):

/*
 * File:   main.c
 * Author: WilsonDR
 *
 * Created on November 27, 2021, 3:22 PM
 * 
 * Flash Programmer
 * 
 * This code can program the Microchip SST39SF010A, SST39SF020A, and SST39SF040A Flash memory ICs
 *  
 * Version History:
 *          1.0.0.0     Initial version
 *          1.1.0.0     Remove dependence on sscanf and sprintf to free up program memory
 *          1.2.0.0     Change serial port routines to work with lengths vice termination character
 *                      Add ATR for identification, add Flash read routine
 *          1.3.0.0     Reprogram to remote the low-order shift register and use port A instead for speed improvement.
 *          1.4.0.0     Implemented chip erase, flash write, sector erase, and changed all lengths to unsigned short vice unsigned char.
 *          1.4.1.0     Recompiled for PIC16F15254 (4K word) vice 16F15256
 * 
 * Inputs:  USART_PICRX UART receive (DTE -> DCE, i.e. computer to PIC)
 * Outputs: USATY_PICTX UART transmit (DCE -> DTE, i.e. PIC to computer)
 *          LED_PICRX   LED for receive
 *          LED_PICTX   LED for transmit
 *          SR_SDATA    Serial data to go out to shift registers
 *          SR_SCLK     Serial clock for shift registers
 *          SR_RCLK     Register clock for shift registers
 *          FL_WE       Write Enable for Flash
 *          FL_ADDRL    Low-order 8 bits of address
 *          FL_DATATRIS Tri-state register for the Flash data port
 * Bidir:   FL_DATA     Data bus to Flash
 */

#include <xc.h>
#include <string.h>
#include "pic16f15254.h"
#include "conbits.h"
#include "USART.h"
#include "flash.h"
#include "pins.h"

// Constants
#define         ATR_SIZE    12
unsigned char   ATR[ATR_SIZE] = {0x3b,0x38,0x45,0x00,'F','l','s','h','P','r','g',0x12};

// Variables
// Buffers
unsigned char   cmdBuf[5];              // Buffer for reading commands
unsigned char   ackBuf[2];              // Buffer for sending acknowledgements
unsigned char   dataBuf[256];           // Buffer for reading input

// Parameters
unsigned char   cmd;                    // Holds the command
unsigned long   addr;                   // Holds the address given on the command line
unsigned short  numBytes;               // Holds the number of bytes to read/write

// Return values
unsigned char   successful;             // Flag to hold whether the operation was successful
unsigned short  numRetBytes;            // Number of bytes to return from dataBuf
unsigned char   returnBytes;            // Flag to hold whether we will return bytes or not

// Interrupt Service Routine (ISR) Declaration
void __interrupt() isr(void);

// Function Declarations

// Main
void main(void) {
    // Local Variables
    unsigned char successful;
    
    // Set up Oscillator
    OSCENbits.HFOEN=1;              // Enable high-frequency oscillator
    OSCFRQ=5;                       // Set for 32 MHz
    while (!OSCSTATbits.HFOR);      // Wait until oscillator is ready

    // Standard port initialization
    ANSELA=0;                       // Disable analog functions, use digital GPIO
    ANSELB=0;
    ANSELC=0;
    WPUA=0;                         // Disable weak pull-up on all pins
    WPUB=0;
    WPUC=0;
    INLVLA=0;                       // Set input level for all pins to TTL-compatible
    INLVLB=0;
    INLVLC=0;
    SLRCONA=0;                      // Set all pin slew rates to maximum
    SLRCONB=0;
    SLRCONC=0;
    ODCONA=0;                       // Turn off open-drain on all pins, act as standard push-pull driver
    ODCONB=0;
    ODCONC=0;
    TRISA=0;                        // Set all pins as output
    TRISB=0;
    TRISC=0;
    
    // Pin initialization for shift registers and data port
    SR_SDATA=1;                     // Serial data out
    SR_SCLK=0;                      // Serial clock
    SR_RCLK=0;                      // Register clock
    FL_WE=1;                        // !Write Enable
    
    successful=clearAddressRegisters();     // Set all address lines low (address 0x000000), set !CE and !OE to high (not enabled)
    FL_DATATRIS=0xff;               // Data port as input
    
    
    // Now set up pins for this application
    // Serial port setup
    SerialPortSetup();
    
    // Enable interrupts
    INTCONbits.PEIE=1;              // Enable peripheral interrupts
    ei();                           // Enable global interrupts

    // Send an Answer to Reset (ATR)
    SerialPortSendData(ATR,ATR_SIZE);

    // Main Loop
    while (1) {
        // Init
        cmd=0;
        numBytes=0;
        addr=0;
        successful=0;
        numRetBytes=0;
        returnBytes=0;
        
        // Receive a 5-byte command into the cmdBuf
        SerialPortReceiveData(cmdBuf,0x05);
        
        // Parse the command, obtain parameters, and dispatch
        switch (cmdBuf[0]) {
            case 0x80:
                // Read Flash command
                // Get address
                addr=((unsigned long)cmdBuf[1]<<16 | (unsigned long)cmdBuf[2]<<8 | (unsigned long)cmdBuf[3]);
                // Get number of bytes to read
                numBytes=(cmdBuf[4]==0x00 ? 0x100 : cmdBuf[4]);             // Protocol with host dictates that 0x00 length = 256 bytes

                // Dispatch the command
                successful=readFlash(addr,numBytes,dataBuf,&numRetBytes);
                
                // Set up the ack buffer
                if (successful) {
                    ackBuf[0]=0x81;
                    ackBuf[1]=(unsigned char)numRetBytes;                   // Protocol with host dictates that 0x00 length = 256 bytes
                    returnBytes=1;
                } else {
                    ackBuf[0]=0xC0;
                    returnBytes=0;
                }
                break;
            case 0x81:
                // Write Flash command
                // Get address
                addr=((unsigned long)cmdBuf[1]<<16 | (unsigned long)cmdBuf[2]<<8 | (unsigned long)cmdBuf[3]);
                // Get number of bytes to write
                numBytes=(cmdBuf[4]==0x00 ? 0x100 : cmdBuf[4]);             // Protocol with host dictates that 0x00 length = 256 bytes
                
                // Set up the ack buffer, this will ask the PC to send numBytes of data to write
                ackBuf[0]=0x91;
                ackBuf[1]=(unsigned char)numBytes;                          // Protocol with host dictates that 0x00 length = 256 bytes
                SerialPortSendData(ackBuf,2);
                
                // Receive those bytes to the dataBuf
                SerialPortReceiveData(dataBuf,numBytes);
                
                // Dispatch the command
                successful=writeFlash(addr,numBytes,dataBuf);
                // Set up the ack buffer
                if (successful) {
                    ackBuf[0]=0x80;
                    returnBytes=0;
                } else {
                    ackBuf[0]=0xC0;
                    returnBytes=0;
                }
                break;
            case 0x82:
                // Sector erase command
                // Get address
                addr=((unsigned long)cmdBuf[1]<<16 | (unsigned long)cmdBuf[2]<<8 | (unsigned long)cmdBuf[3]);
                // Number of bytes is not relevant, we will only erase 1 sector
                // It will be the 4K sector where the address falls (sector starting addresses are on 4K boundaries)
                
                // Make the address a 4K boundary address
                addr&=0xfff000;
                
                // Dispatch the command
                successful=eraseFlashSector(addr);
                
                // Set up the ack buffer
                if (successful) {
                    ackBuf[0]=0x80;
                    returnBytes=0;
                } else {
                    ackBuf[0]=0xC0;
                    returnBytes=0;
                }
                break;
             case 0x83:
                // Get Flash Chip ID command
                
                // Dispatch the command
                successful=readFlashChipId(dataBuf,&numRetBytes);
                
                // Set up the ack buffer
                if (successful) {
                    ackBuf[0]=0x81;
                    ackBuf[1]=(unsigned char)numRetBytes;                   // Protocol with host dictates that 0x00 length = 256 bytes;
                    returnBytes=1;
                } else {
                    ackBuf[0]=0xC0;
                    returnBytes=0;
                }
                break;
            case 0x84:
                // Chip Erase command
                
                // Dispatch the command
                successful=eraseFlash();
                
                // Set up the ack buffer
                if (successful) {
                    ackBuf[0]=0x80;
                    returnBytes=0;
                } else {
                    ackBuf[0]=0xC0;
                    returnBytes=0;
                }
                break;
            case 0xbf:
                // Software reset
                // Just return from main and the chip will restart
                return;
                break;
            default:
                break;
        }

        // Send the acknowledgement from the ack buffer and any data bytes
        SerialPortSendData(ackBuf,(returnBytes+1));
        if (returnBytes) SerialPortSendData(dataBuf,numRetBytes);
    }    
    return;
}

// Interrupt Service Routine (ISR)
void __interrupt() InterruptServiceRoutine(void) {
    // Interrupt Service Routine
    
    // See if this interrupt is a UART transmit interrupt
    if (PIE1bits.TX1IE & PIR1bits.TX1IF) {
        SerialPortTransmitInterruptService();
    }
    
    // See if this interrupt is a UART receive interrupt
    if (PIE1bits.RC1IE & PIR1bits.RC1IF) {
        SerialPortReceiveInterruptService();
    }
}

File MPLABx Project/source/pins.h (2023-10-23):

/* 
 * File:                pins.h
 * Author:              Dan Wilson
 * Comments:
 * Revision history:    
 */

#ifndef XC_HEADER_PINS_H
#define	XC_HEADER_PINS_H

#include <xc.h> // include processor files - each processor file is guarded.  

// These definitions are to attach convenient names to pins
/*
 * Inputs:  PORTC[7]    UART receive (DTE -> DCE, i.e. computer to PIC)
 * Outputs: PORTC[6]    UART transmit (DCE -> DTE, i.e. PIC to computer)
 *          PORTC[5]    LED for receive
 *          PORTC[4]    LED for transmit
 *          PORTC[0]    Serial data to go out to shift registers
 *          PORTC[1]    Serial clock for shift registers
 *          PORTC[2]    Register clock for shift registers
 *          PORTC[3]    Write Enable for Flash
 *          PORTA       Low-order 8 bits of address
 * Bidir:   PORTB       Data bus to Flash
*/

#define     USART_PICRX     LATCbits.LATC7
#define     USART_PIXTX     LATCbits.LATC6
#define     LED_PICRX       LATCbits.LATC5
#define     LED_PICTX       LATCbits.LATC4
#define     SR_SDATA        LATCbits.LATC0
#define     SR_SCLK         LATCbits.LATC1
#define     SR_RCLK         LATCbits.LATC2
#define     FL_WE           LATCbits.LATC3
#define     FL_ADDRL        PORTA
#define     FL_DATA         PORTB
#define     FL_DATATRIS     TRISB

#endif	/* XC_HEADER_PINS_H */

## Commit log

2023-10-23 v1.0.0.0
    Flash Programmer for SST39 devices.
2023-10-23 Add .zip file for PCBs

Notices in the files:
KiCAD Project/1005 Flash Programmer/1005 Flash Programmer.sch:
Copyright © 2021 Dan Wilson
